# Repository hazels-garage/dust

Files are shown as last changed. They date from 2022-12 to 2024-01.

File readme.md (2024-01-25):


<a href="https://shop.hazel.cc/">
 
</a>
<a href="https://discord.gg/jP6hvgNN8r">
  
</a>

# dust
## ultrathin sweep-alike

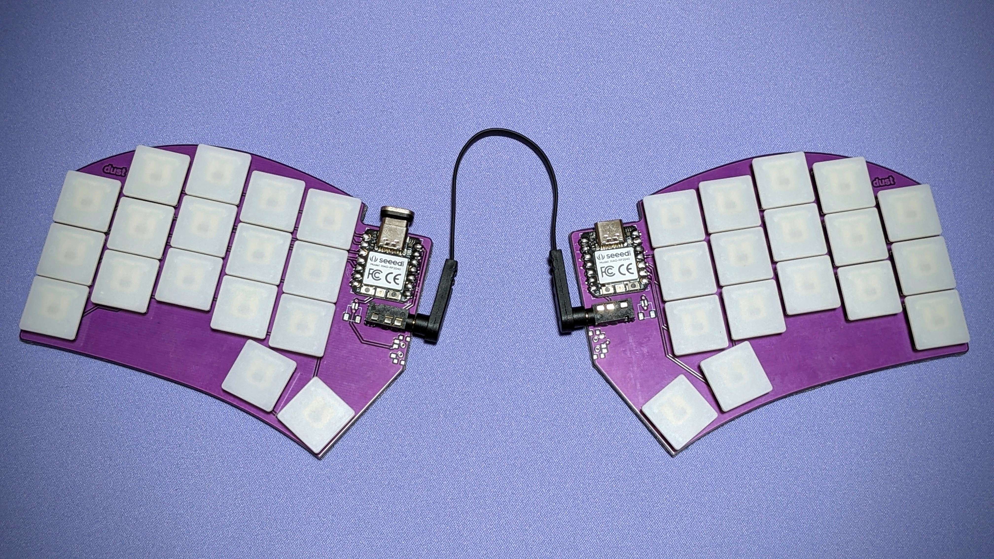
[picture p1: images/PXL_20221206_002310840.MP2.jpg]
top

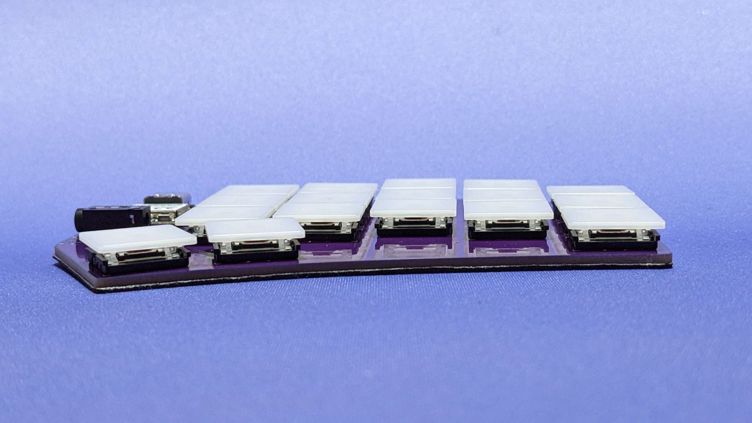
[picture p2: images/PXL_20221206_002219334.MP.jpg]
side


| Left | Right |
| :---: | :---: |
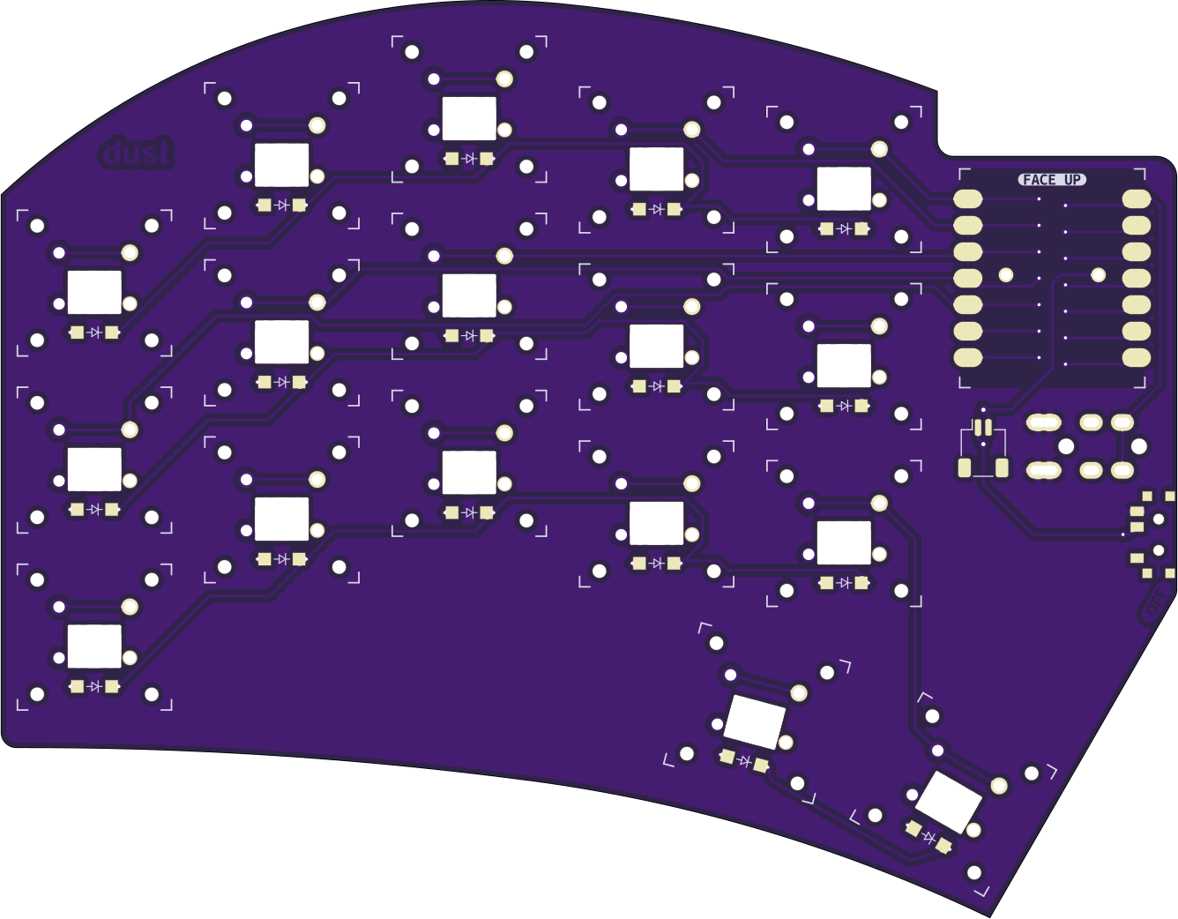
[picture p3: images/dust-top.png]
left
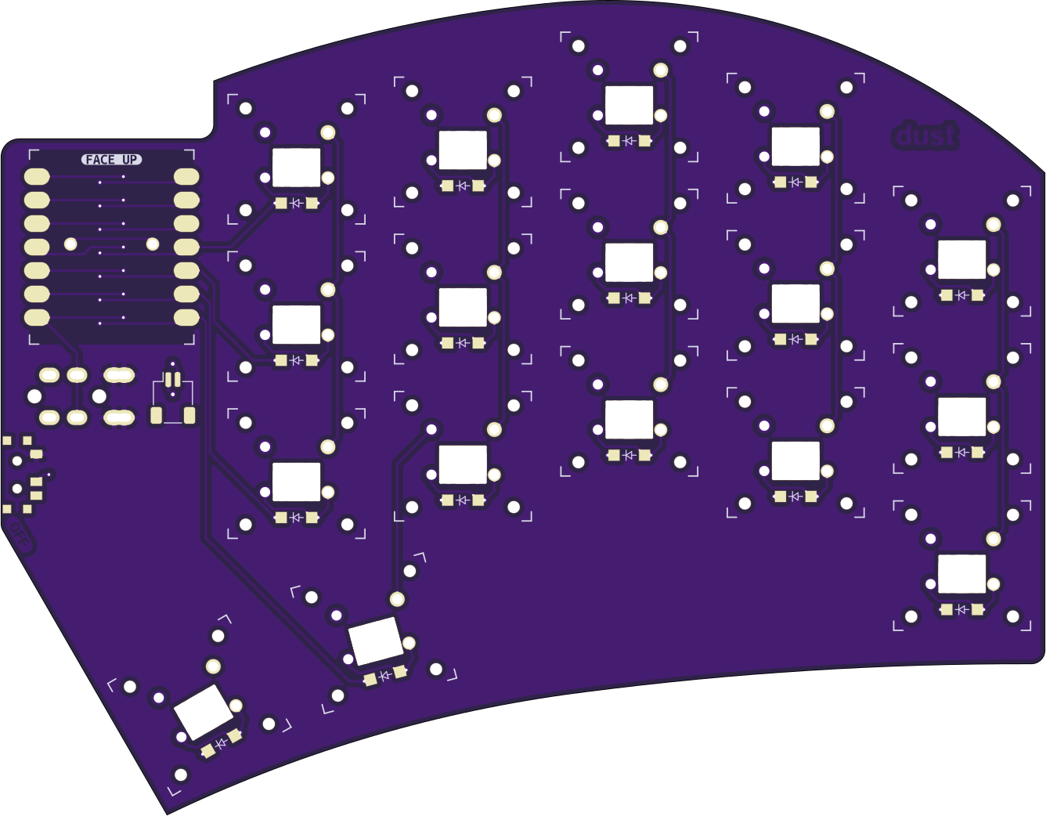
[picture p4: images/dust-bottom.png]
right
|  |  |

**dust** is my attempt at making the thinnest sweep-alike.
### Sacrifices were made.  

- XIAO is surface mounted to be reversible without jumpers.  
- There is no reset button because the xiao has one on it.  
- Soldering the battery connection on the XIAO is gonna suck.
- You're probably gonna need to tape the battery to the board.

## MATERIALS
- 34x [Kailh X Switches](https://www.aliexpress.us/item/2251832799288171.html)
- 34x [1N4148 - SOD-123 Diodes](https://www.aliexpress.us/item/3256801606142520.html)
- 2x SeeedStudio XIAO (RP2040 or BLE)
- 2x [TRRS Jack](https://www.aliexpress.us/item/3256801742337046.html) (RP2040)
- 2x [Power Switch](https://mkultra.click/alps-ssss811101/) (BLE)
- 2x [Battery](https://tinycircuits.com/collections/all/products/lithium-ion-polymer-battery-3-7v-40mah) (BLE)
- 2x [Battery Connector](https://www.aliexpress.us/item/3256803789364982.html) (BLE)

## CASE
3D Printable case designed by ant: [Dust Tray](https://github.com/Ant6009/Dust_Tray)

## FIRMWARE

[QMK](https://github.com/jasonhazel/qmk_hazel/tree/master/keyboards/jasonhazel/dust)

[ZMK](https://github.com/jasonhazel/zmk-config/tree/master/config/boards/shields/dust)

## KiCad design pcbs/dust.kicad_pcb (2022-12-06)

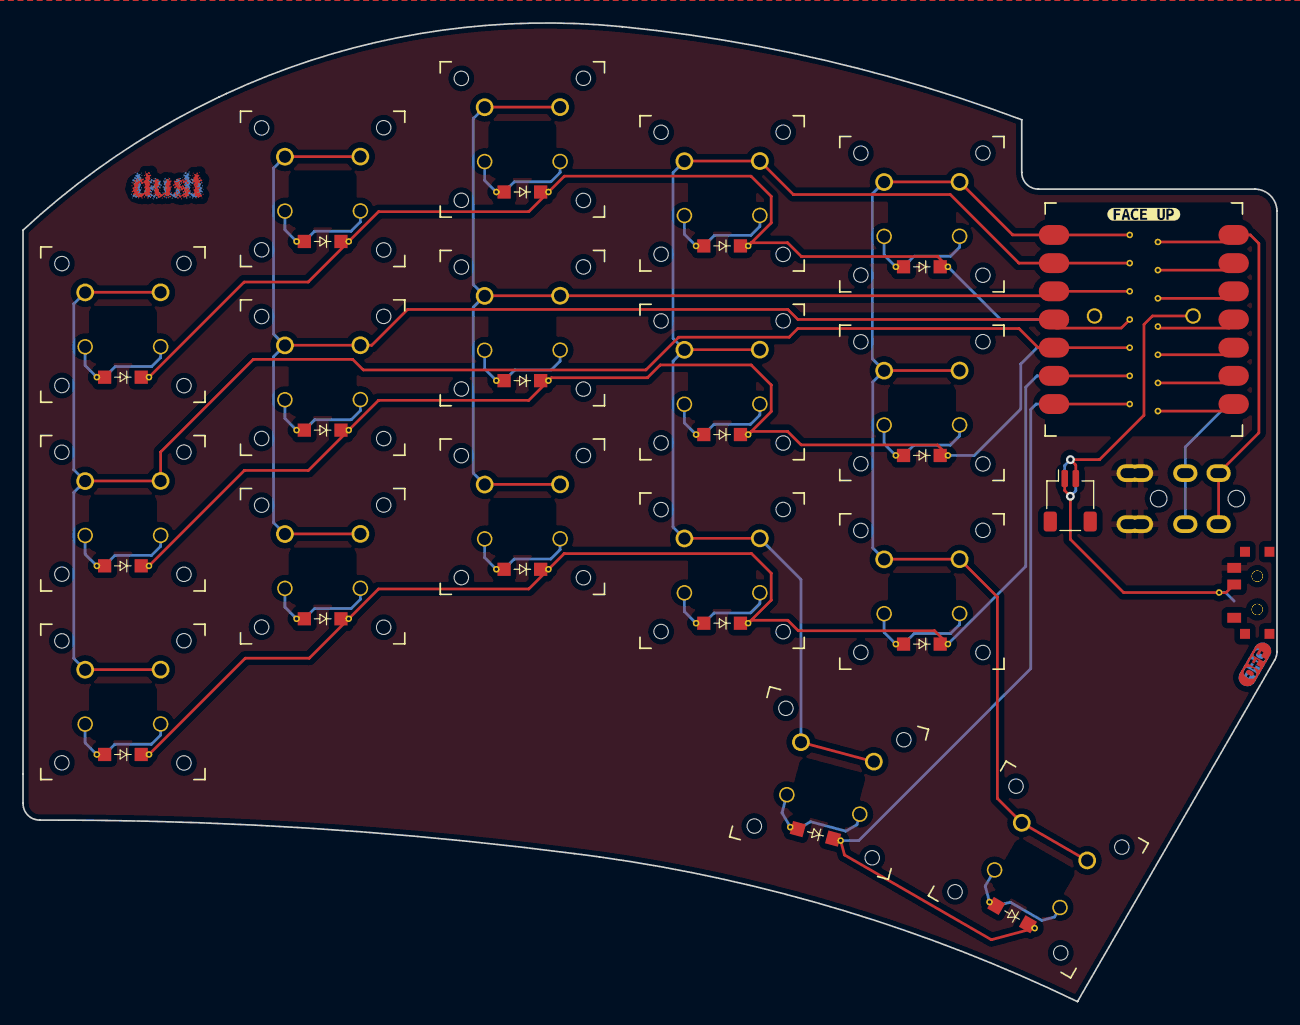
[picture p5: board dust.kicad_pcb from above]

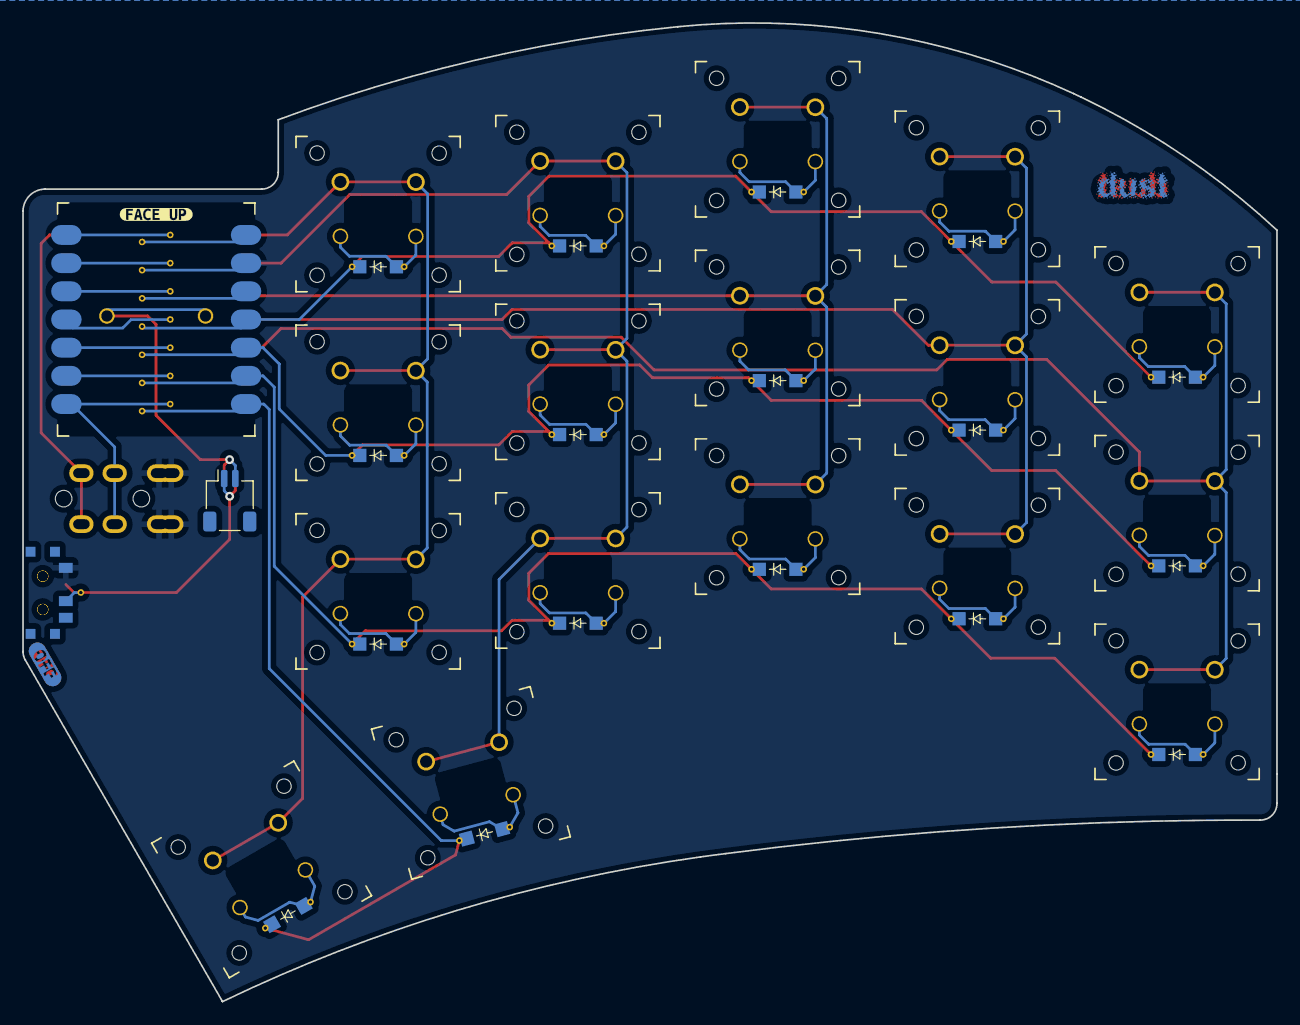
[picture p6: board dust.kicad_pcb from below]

Board: 2 copper layers, 113.0 x 88.2 mm, 43 parts (4 on the bottom side), 29 nets.

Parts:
BT2, BT2#2: Battery_Cell; JST_SH_SM02B-SRSS-TB_1x02-1MP_P1.00mm_Horizontal
D1, D2, D3, D4, D5, D6, D7, D8, D9, D10, D11, D12, D13, D14, D15, D16, D17: ComboDiode
S1, S2, S3, S4, S5, S6, S7, S8, S9, S10, S11, S12, S13, S14, S15, S16, S17: Kailh-PG1425-X-Switch-revers
T1, T1#2: SPDT_C128955
XIAO1: xiao-rev
kibuzzard-637F21E7, kibuzzard-637F21E7#2: G***; kibuzzard-637F21E7
kibuzzard-6383179D, kibuzzard-6383179D#2: G***; kibuzzard-6383179D

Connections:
BAT: BT2.2, BT2#2.2, XIAO1.19
BAT-: BT2.1, BT2#2.1, T1.2, T1#2.2
GND: T1.3, T1#2.1, XIAO1.13
c0: S1.1, S2.1, S3.1, XIAO1.5
c1: S4.1, S5.1, S6.1, XIAO1.4
c2: S7.1, S8.1, S9.1, XIAO1.3
c3: S10.1, S11.1, S12.1, S17.1, XIAO1.2
c4: S13.1, S14.1, S15.1, S16.1, XIAO1.1
index_bottom: D10.2, S10.2
index_home: D11.2, S11.2
index_top: D12.2, S12.2
inner_bottom: D13.2, S13.2
inner_home: D14.2, S14.2
inner_top: D15.2, S15.2
middle_bottom: D7.2, S7.2
middle_home: D8.2, S8.2
middle_thumb: D17.2, S17.2
middle_top: D9.2, S9.2
pinky_bottom: D1.2, S1.2
pinky_home: D2.2, S2.2
pinky_top: D3.2, S3.2
r0: D16.1, D17.1, XIAO1.8
r1: D1.1, D4.1, D7.1, D10.1, D13.1, XIAO1.9
r2: D2.1, D5.1, D8.1, D11.1, D14.1, XIAO1.10
r3: D3.1, D6.1, D9.1, D12.1, D15.1, XIAO1.11
right_thumb: D16.2, S16.2
ring_bottom: D4.2, S4.2
ring_home: D5.2, S5.2
ring_top: D6.2, S6.2

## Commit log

2022-12-06 slight changes to pcb
    [dust.kicad_pcb]
2023-03-02 case link
    added link to case from ant.

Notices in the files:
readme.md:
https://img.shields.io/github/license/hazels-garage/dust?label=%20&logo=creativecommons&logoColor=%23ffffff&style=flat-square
